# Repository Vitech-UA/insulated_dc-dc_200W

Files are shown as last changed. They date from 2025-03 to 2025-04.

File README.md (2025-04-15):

## Вигляд Віртуального пристрою. Без радіатора



## Вигляд Зібраного DC-DC. З радіатором
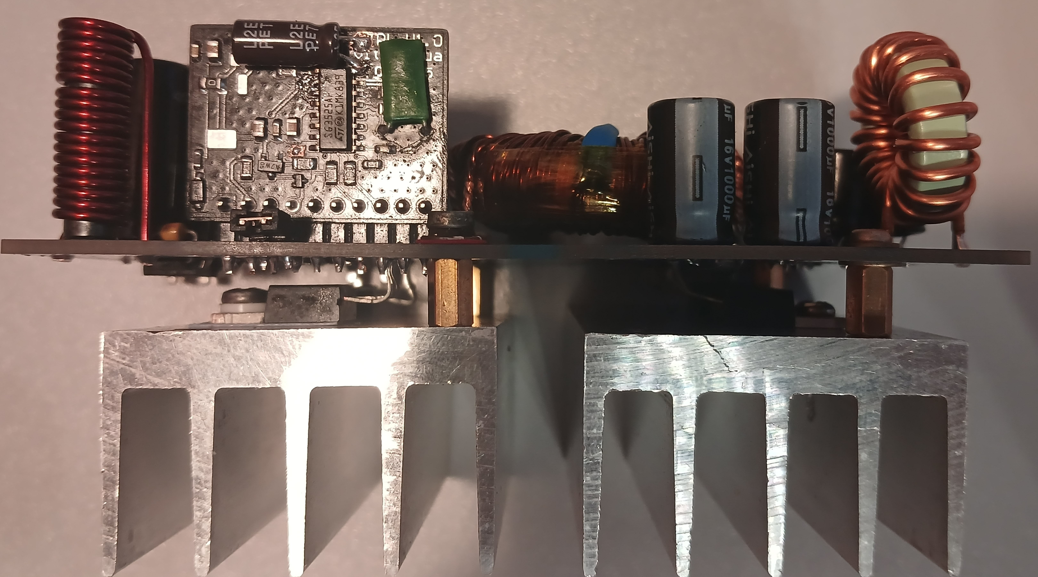
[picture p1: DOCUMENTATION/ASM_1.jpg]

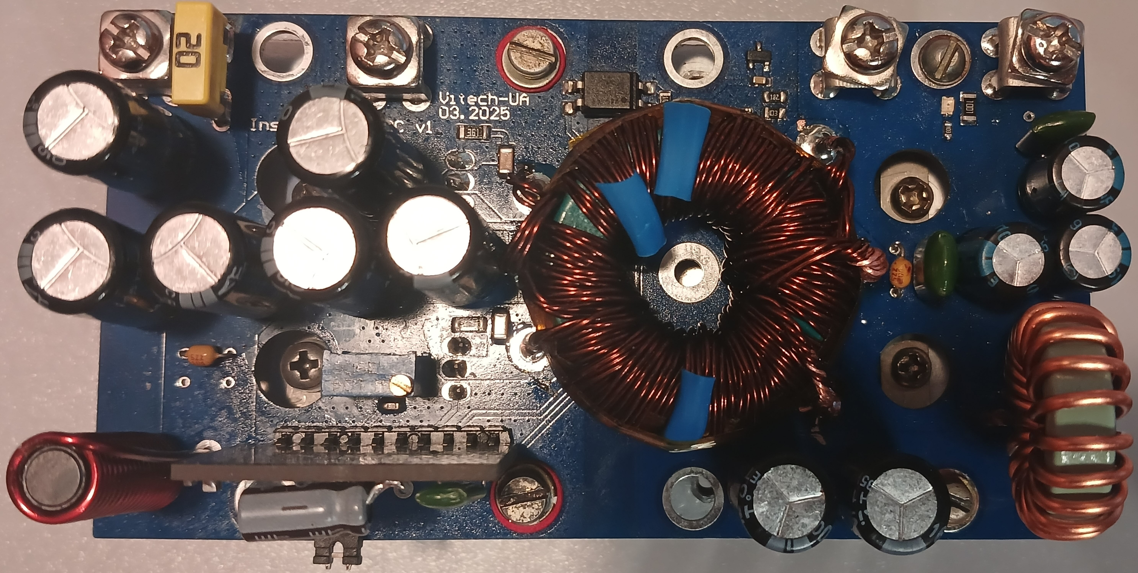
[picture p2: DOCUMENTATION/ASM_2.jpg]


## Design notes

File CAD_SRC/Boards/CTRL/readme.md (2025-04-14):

## Схема плати контроллера US3525


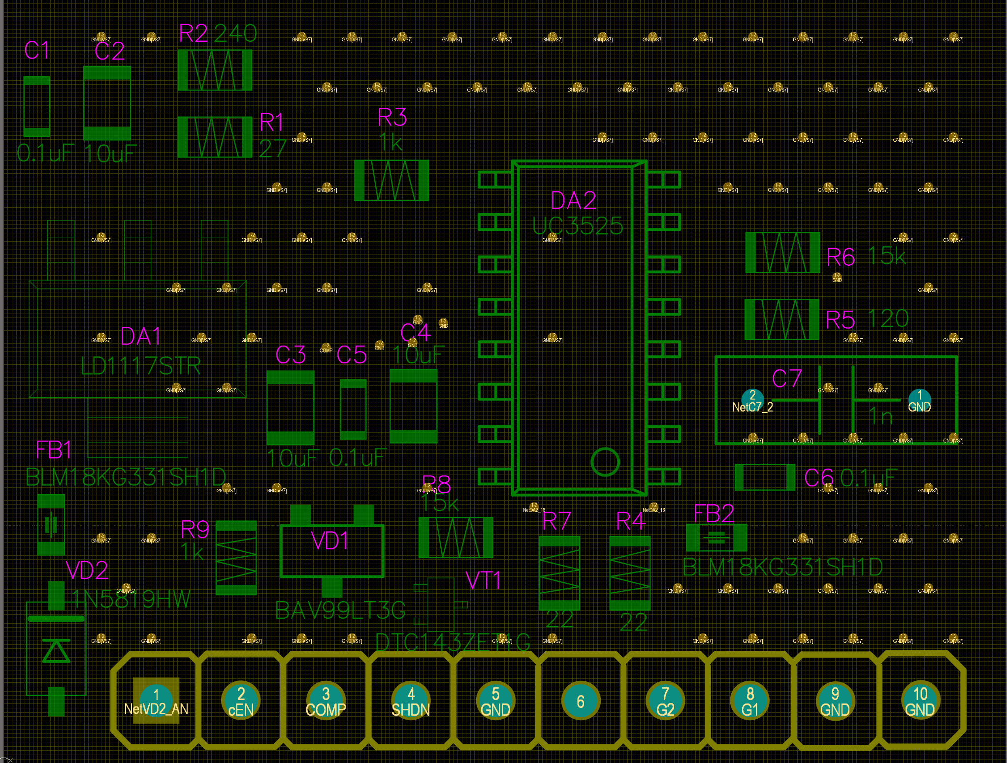
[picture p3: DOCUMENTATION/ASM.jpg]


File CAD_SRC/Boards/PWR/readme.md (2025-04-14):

## SCH PWRv1.0


## TOP VIEW PWRv1.0


## BOTTOM VIEW PWRv1.0


## SOLDERMAP
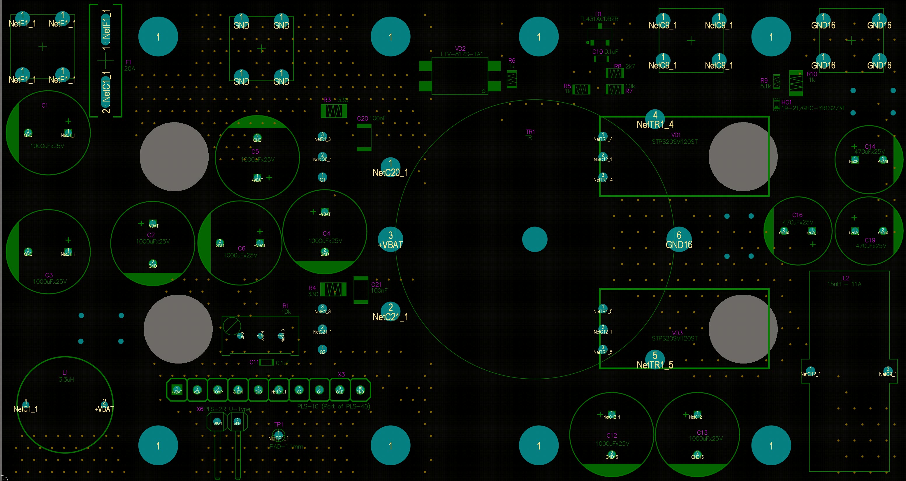
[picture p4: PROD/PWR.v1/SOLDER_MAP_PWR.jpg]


## Розрахунок трансформатора
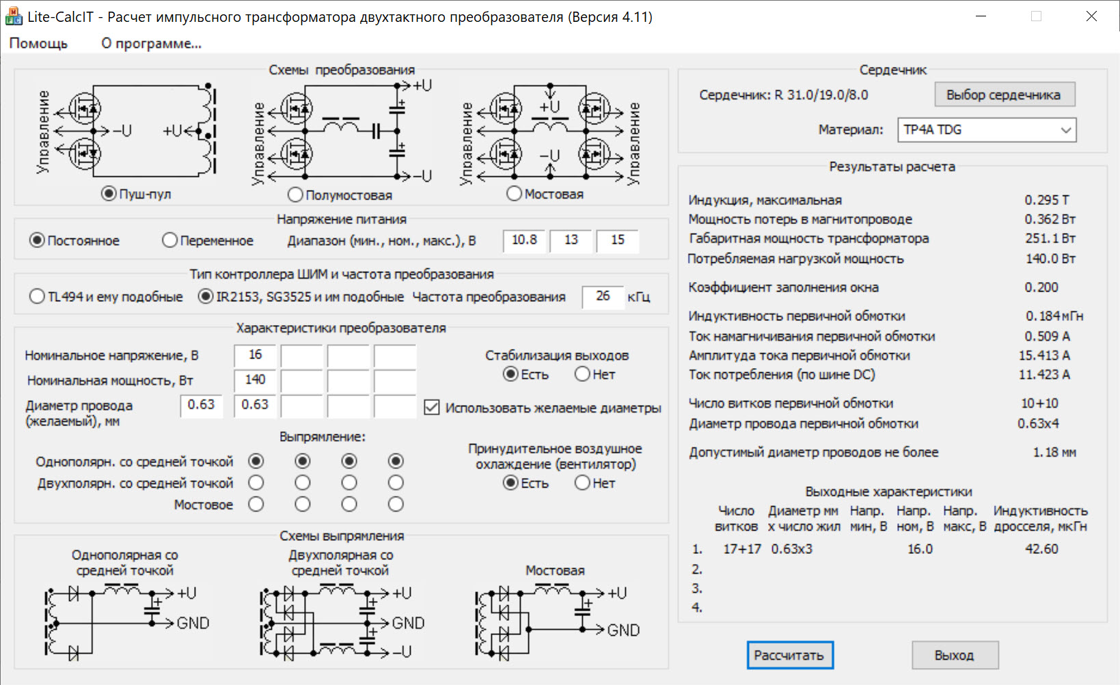
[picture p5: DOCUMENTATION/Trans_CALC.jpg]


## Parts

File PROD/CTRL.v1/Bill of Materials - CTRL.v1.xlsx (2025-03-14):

Project name | CTRL.PrjPcb
Revision | v1
Assembly variant | None
Engineer(s) | Vitech
Document timestamp | 14.03.2025
 | 23:17
Technical information |  |  |  |  |  |  |  | Additional information
Designator | Manufacturer | Part Number | Value | Tolerance | Voltage | Component Type | Package | Quantity | Comment | Description
C1, C5, C6 | Samsung Electro-Mechanics | CL10B104KB8NNNC | 0.1uF | ±10% | 50V | SMD | 0603 | 3 | 0.1uF | 100nF 50V X7R ±10% 0603 Ceramic Capacitor RoHS
C2 | TDK Corporation | C2012X5R1V106K125AC | 10uF | ±10% | 35V | SMD | 0805 | 1 | 10uF | 10uF 35V X5R ±10% 0805 Low ESL Ceramic Capacitor RoHS
C3, C4 | TDK Corporation | C2012X5R1E106M085AC | 10uF | ±20% | 25V | SMD | 0805 | 2 | 10uF | 10uF 25V X5R ±20% 0805 Ceramic Capacitor RoHS
C7 | Murata | GRM31CR71E106KA12L | 1n | 10 % | *V | THT | 1206 | 1 | 1n | Multilayer Ceramic Capacitors MLCC - SMD/SMT 10 uF 25 VDC 10% 1206 X7R
DA1 | STMicroelectronics | LD1117STR |  |  |  | SMD | SOT-223 | 1 | LD1117STR | Adjustable Low Drop Positive Voltage Regulator, 1.25V to 15V, 800mA
DA2 | Texas | UC3825 |  |  |  | SMD | DIP16 | 1 | UC3525 | Buck, Push-Pull Regulator Positive Output Step-Down, Step-Up/Step-Down DC-DC Controller IC 16-DIP/16-SOIC
FB1, FB2 | Murata Electronics | BLM18KG331SH1D | 330 Ohms @ 100MHz | ±25% |  | SMD | 0603 | 2 | BLM18KG331SH1D | 330 Ohms @ 100 MHz Power Line Ferrite Bead 0603, 1.7A 80mOhm
R1 | Yageo | RC0805JR-0722RL | 27 | ±5% | 150V | SMD | 0805 | 1 | 27 | 22 Ohms ±5%, 1/8W 0805 Thick Film Resistor
R2 | Yageo | RC0805JR-0722RL | 240 | ±5% | 150V | SMD | 0805 | 1 | 240 | 22 Ohms ±5%, 1/8W 0805 Thick Film Resistor
R3, R9 | Yageo | RC0805JR-0722RL | 1k | ±5% | 150V | SMD | 0805 | 2 | 1k | 22 Ohms ±5%, 1/8W 0805 Thick Film Resistor
R4, R7 | Yageo | RC0805JR-0722RL | 22 | ±5% | 150V | SMD | 0805 | 2 | 22 | 22 Ohms ±5%, 1/8W 0805 Thick Film Resistor
R5 | Yageo | RC0805JR-0722RL | 120 | ±5% | 150V | SMD | 0805 | 1 | 120 | 22 Ohms ±5%, 1/8W 0805 Thick Film Resistor
R6, R8 | Yageo | RC0805JR-0722RL | 15k | ±5% | 150V | SMD | 0805 | 2 | 15k | 22 Ohms ±5%, 1/8W 0805 Thick Film Resistor
VD1 | Onsemi | BAV99LT3G |  |  | 100V | SMD | SOT-23 | 1 | BAV99LT3G | Diode Array 1 Pair Series Connection, Standard, 100V, 215mA (DC), SOT-23
VD2 | Nexperia USA | 1N5819HW |  |  | 75V | SMD | SOD-123 | 1 | 1N5819HW | Diode Standart 75V 215mA, SOD-123
VT1 | Onsemi | DTC143ZET1G |  |  |  | SMD | SC-75 | 1 | DTC143ZET1G | 50V, 100mA Low Vce(sat) NPN Digital Transistor, Pre-Biased 4.7k/47k (with built-in resistors)
X1 | Connfly | DS1021-10SF11 |  |  |  | PTH |  | 1 | PLS-10 (Part of PLS-40) | 10 Pin 2.54mm Male Header, Vertical, 3mm and 6.1mm, PLS-5

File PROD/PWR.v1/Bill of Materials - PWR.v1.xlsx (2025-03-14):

Product name | INS.DCDC |  |  |  |  |  |  |  |  |  | Template version 1.0.1
Project name | PWR.PrjPcb
Revision | v1
Assembly variant | None
Engineer(s) | Starovit
Document timestamp | 14.03.2025
 | 23:23
Technical information |  |  |  |  |  |  |  | Additional information
Designator | Manufacturer | Part Number | Value | Tolerance | Voltage | Component Type | Package | Quantity | Comment | Description
C1, C2, C3, C4, C5, C6, C12, C13 | Kemet | ESH108M025AH4AA | 1000uF | ±20% | 25V | PTH | D10x20mm | 8 | 1000uFx25V | 1000uF 25V ±20% Aluminum Electrolytic Capacitors Radial, 2000 Hrs @ 105°C, 740mA Ripple Current
C7, C8, C9, C15, C17, C18 | Murata | GRM31CR71E106KA12L | 0.1uF | 10 % | 25V | THT | 1206 | 6 | *uF | Multilayer Ceramic Capacitors MLCC - SMD/SMT 10 uF 25 VDC 10% 1206 X7R
C10, C11 | Samsung Electro-Mechanics | CL10B104KB8NNNC | 0.1uF | ±10% | 50V | SMD | 0603 | 2 | 0.1uF | 100nF 50V X7R ±10% 0603 Ceramic Capacitor RoHS
C14, C16, C19 | Koshin | KS-025V471MF130 | 470uF | ±20% | 25V | PTH | D8x13mm | 3 | 470uFx25V | 470uF 25V ±20% D8x13mm Conductive Polymer Aluminum Solid Capacitor, 2000 Hrs @ 105°C, 4100mA Ripple Current
C20, C21 | Walsin | 1206B102K102CG | 1nF | ±10% | 1000V | SMD | 1206 | 2 | 100nF | 1nF 1000V X7R ±10% 1206 Ceramic Capacitor RoHS
D1 | Texas Instruments | TL431ACDBZR |  |  |  | SMD | SOT-23 | 1 | TL431ACDBZR | Adjustable Precision Shunt Regulator, Accuracy 1%, SOT-23-3
F1 |  |  |  |  |  |  |  | 1 | 20A | Fuse MAXI Size
HG1 | Everlight Electronics | 19-21/GHC-YR1S2/3T |  |  |  | SMD | 0603 | 1 | 19-21/GHC-YR1S2/3T | Indication LED, Green 528nm, Clear, SMD 0603, Vf 2.7-3.7V, 112 - 285mcd @ 20mA, 110°
J1 | Connfly | DS1022-1x2RUF1 |  |  |  | PTH |  | 1 | PLS-2R U-Type | 2 pin Male Header, Right Angle, 2.54mm, PTH, PLS-2R, U-type
L1 | Bourns Inc. | RLB0914-3R3ML-ND | 3.3 uH | ±20% |  |  | THT | 1 | 3.3uH | Дросель з магазину Coretech
L2 | Bourns Inc. | RLB0914-3R3ML-ND | 15 uH | ±20% |  |  | THT | 1 | 15uH
R1 | Bourns | 3296W-1-103LF | 10k | ±10% |  | PTH | 4.83x9.53mm | 1 | 10k | 10 kOhms ±10% Trimmer Resistor, 0.5W, Through Hole 3/8", 4.83x9.53mm, 10.03mm Height
R2, R11, R12 | Bourns | CRA2512-FZ-R030ELF | 40mOhm | ±1% | NONE | SMD | 2512 | 3 | 40mOhm | 30 mOhms ±1%, 3W 2512 Metal Strip Current Sense Chip Resistor
R3, R4 | Vishay | CRCW120675R0FKEAC | 330 | ±1% | 200V | SMD | 1206 | 2 | 330 | 75 Ohms ±1%, 1/4W 1206 Thick Film Resistor
R5, R6 | Yageo | RC0805JR-0722RL | 1k | ±5% | 150V | SMD | 0805 | 2 | 1k | 22 Ohms ±5%, 1/8W 0805 Thick Film Resistor
R7 | Yageo | RC0805JR-0722RL | 10k | ±5% | 150V | SMD | 0805 | 1 | 22 | 22 Ohms ±5%, 1/8W 0805 Thick Film Resistor
R8 | Yageo | RC0805JR-0722RL | 2k7 | ±5% | 150V | SMD | 0805 | 1 | 2k7 | 22 Ohms ±5%, 1/8W 0805 Thick Film Resistor
R9 | Yageo | RC0603FR-075K1L | 5.1k | ±1% | 75V | SMD | 0603 | 1 | 5.1k | 5.1 kOhms ±1%, 1/10W 0603 Thick Film Resistor
R10 | Vishay | CRCW120675R0FKEAC | 1k | ±1% | 200V | SMD | 1206 | 1 | 1k | 75 Ohms ±1%, 1/4W 1206 Thick Film Resistor
TR1 | Handmade | RLB0914-3R3ML-ND |  | ±20% |  |  |  | 1 | TR
VD1, VD3 | STMicroelectronics | STPS20SM120ST |  |  | 120V | PTH | TO-220AB | 2 | DIODE SCHOTTKY | Diode Schottky Array 1 Pair Common Cathode, 120V 20A, TO-220
VD2 | Lite-On Optoelectronics | LTV-817S-TA1 |  |  |  | SMD | SSOP-4 | 1 | LTV-817S-TA1 | 1-Channel Photocoupler, 5kV, SSOP-4
VD5, VD6, VD7 | Onsemi | SS34 |  |  | 40V | SMD | SMC | 3 | SS34 | Diode Schottky 40V 3A, SMC
VT1, VT2 |  | IRF3205 |  |  |  | SMD | D-PAK | 2 | AOD403 | N-MOSFET; полевой;
X1, X2, X4, X5 | China | PCB-2CM3 |  |  |  | PTH |  | 4 | PCB-2CM3 | Гвинтова клема для друкарського монтажу, 40 А Матеріал - латунь луджена 0.8 мм, гвинт в комплекті. Піни 5x7mm
X3 | Connfly | DS1021-10SF11 |  |  |  | PTH |  | 1 | PLS-10 (Part of PLS-40) | 10 Pin 2.54mm Male Header, Vertical, 3mm and 6.1mm, PLS-5

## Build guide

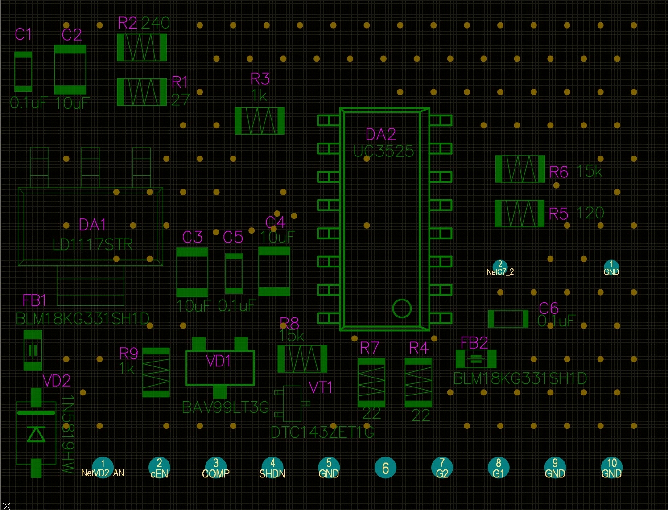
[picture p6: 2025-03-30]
PROD/CTRL.v1/SOLDER_MAP_CTRL.jpg

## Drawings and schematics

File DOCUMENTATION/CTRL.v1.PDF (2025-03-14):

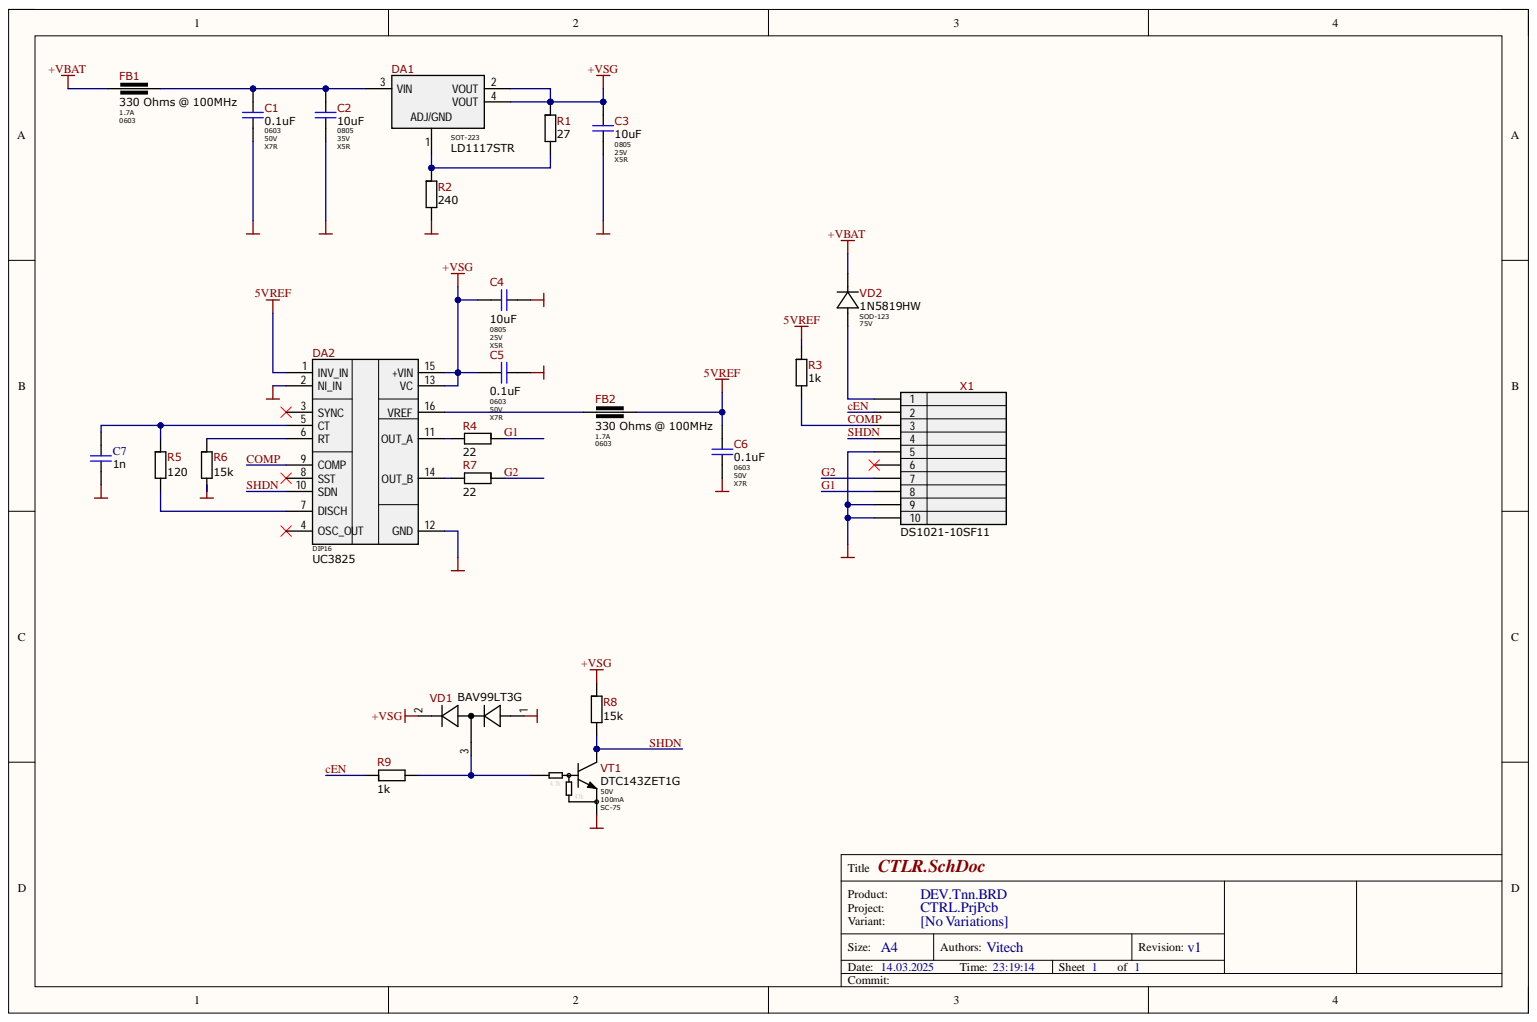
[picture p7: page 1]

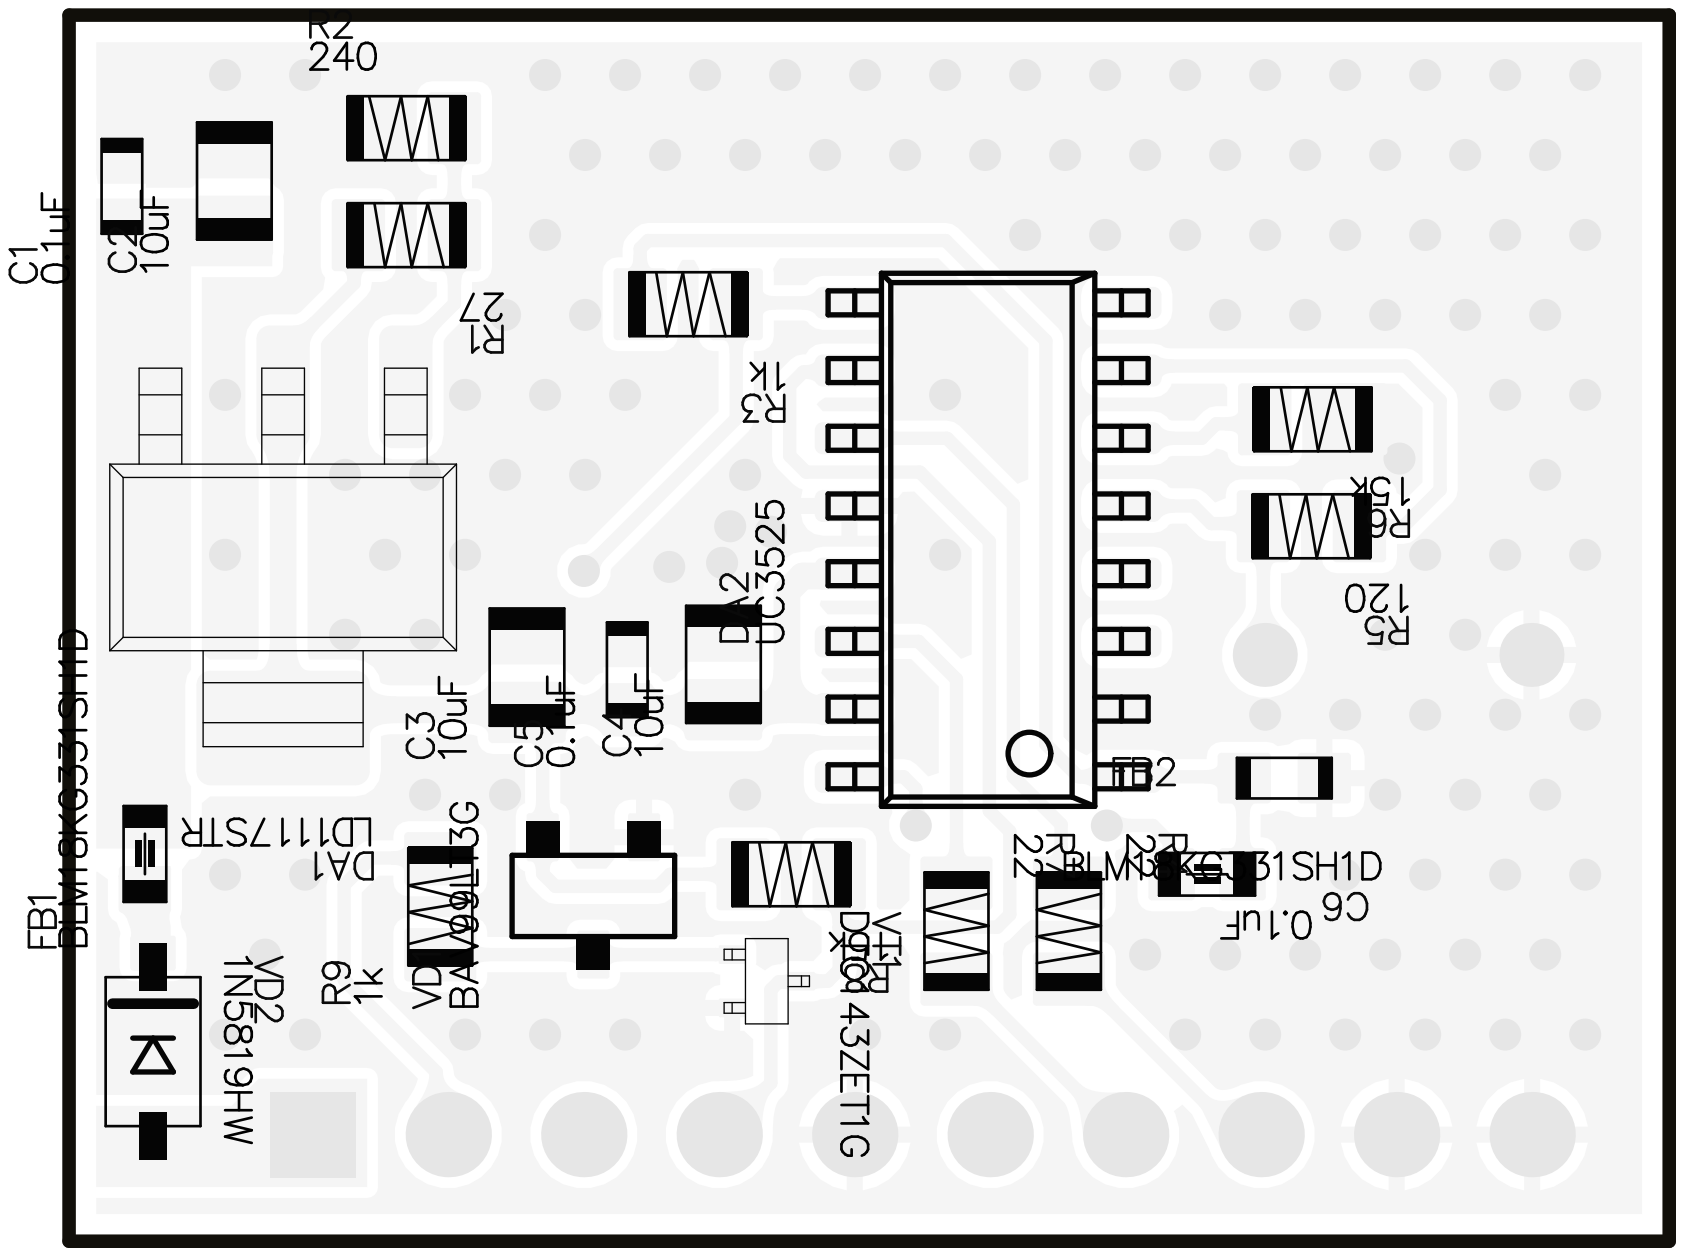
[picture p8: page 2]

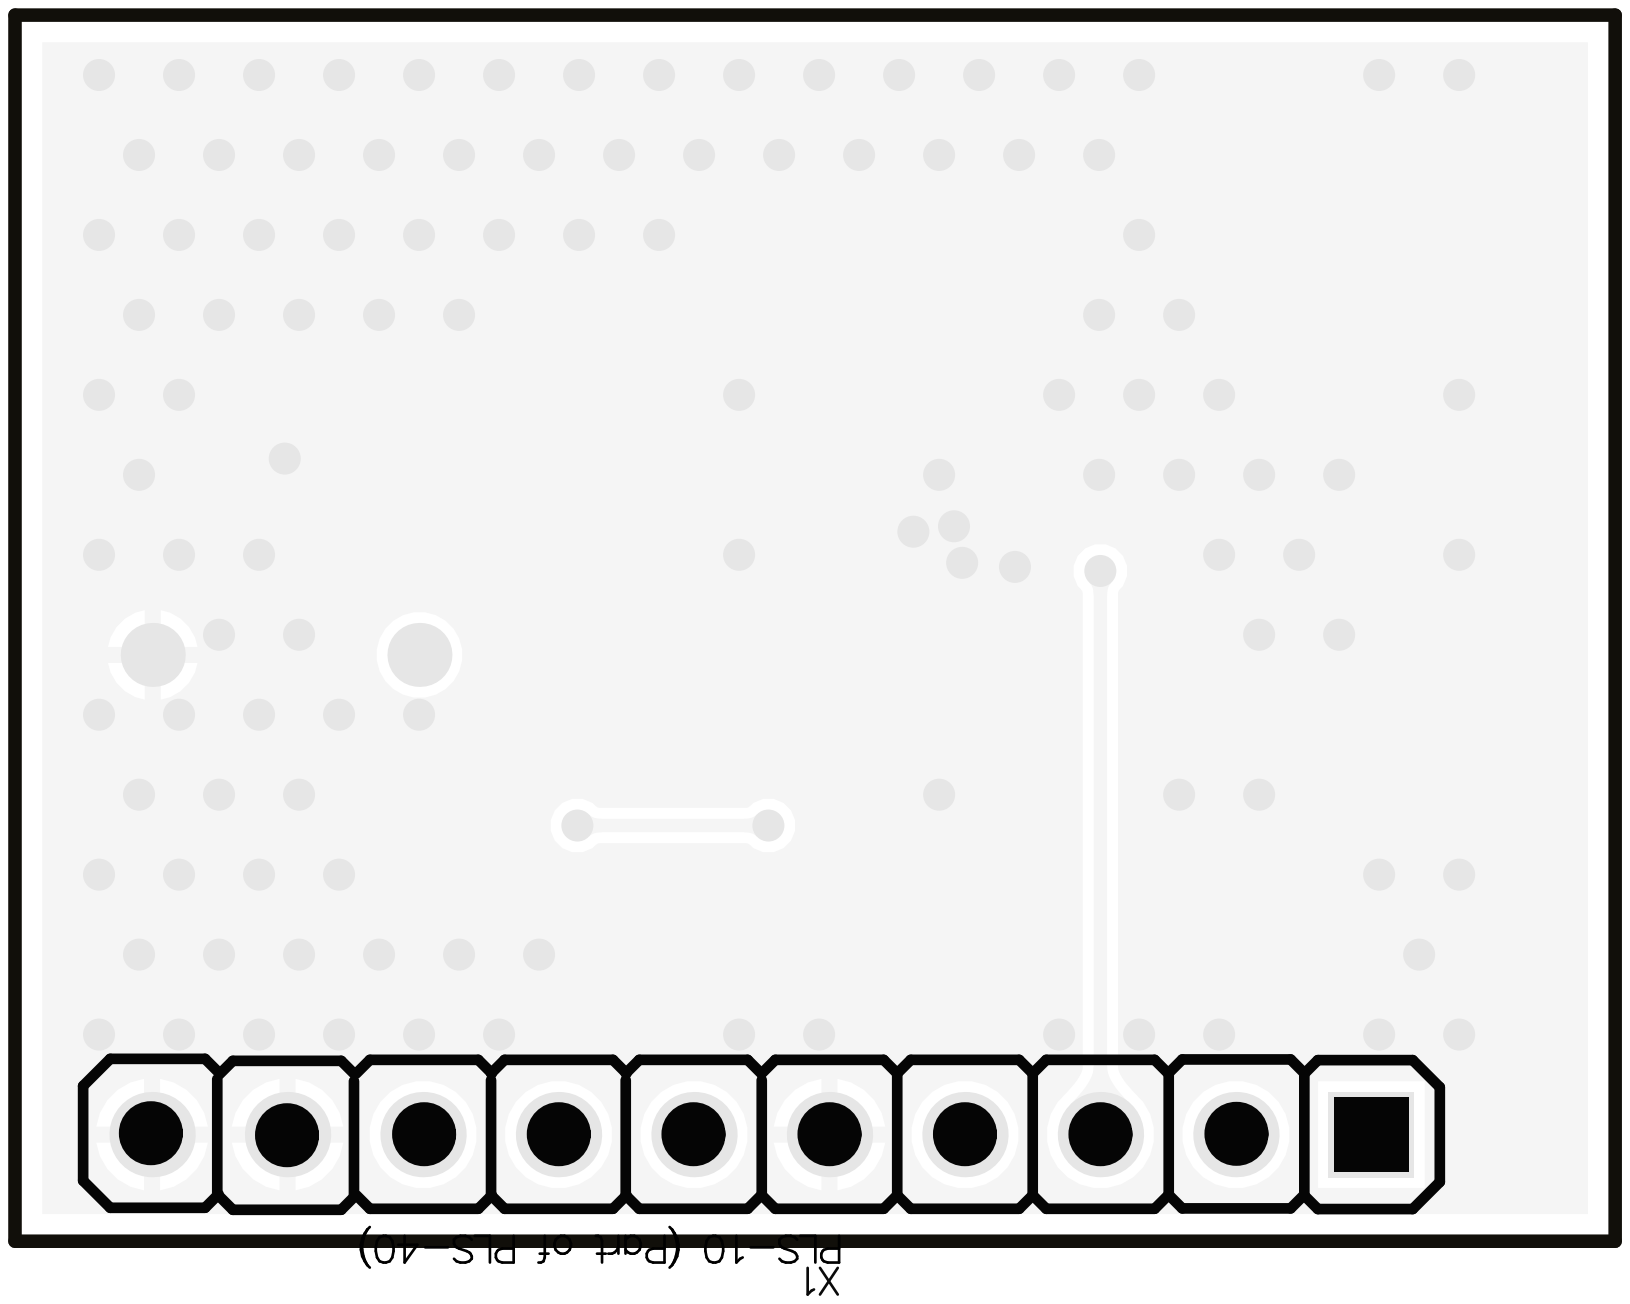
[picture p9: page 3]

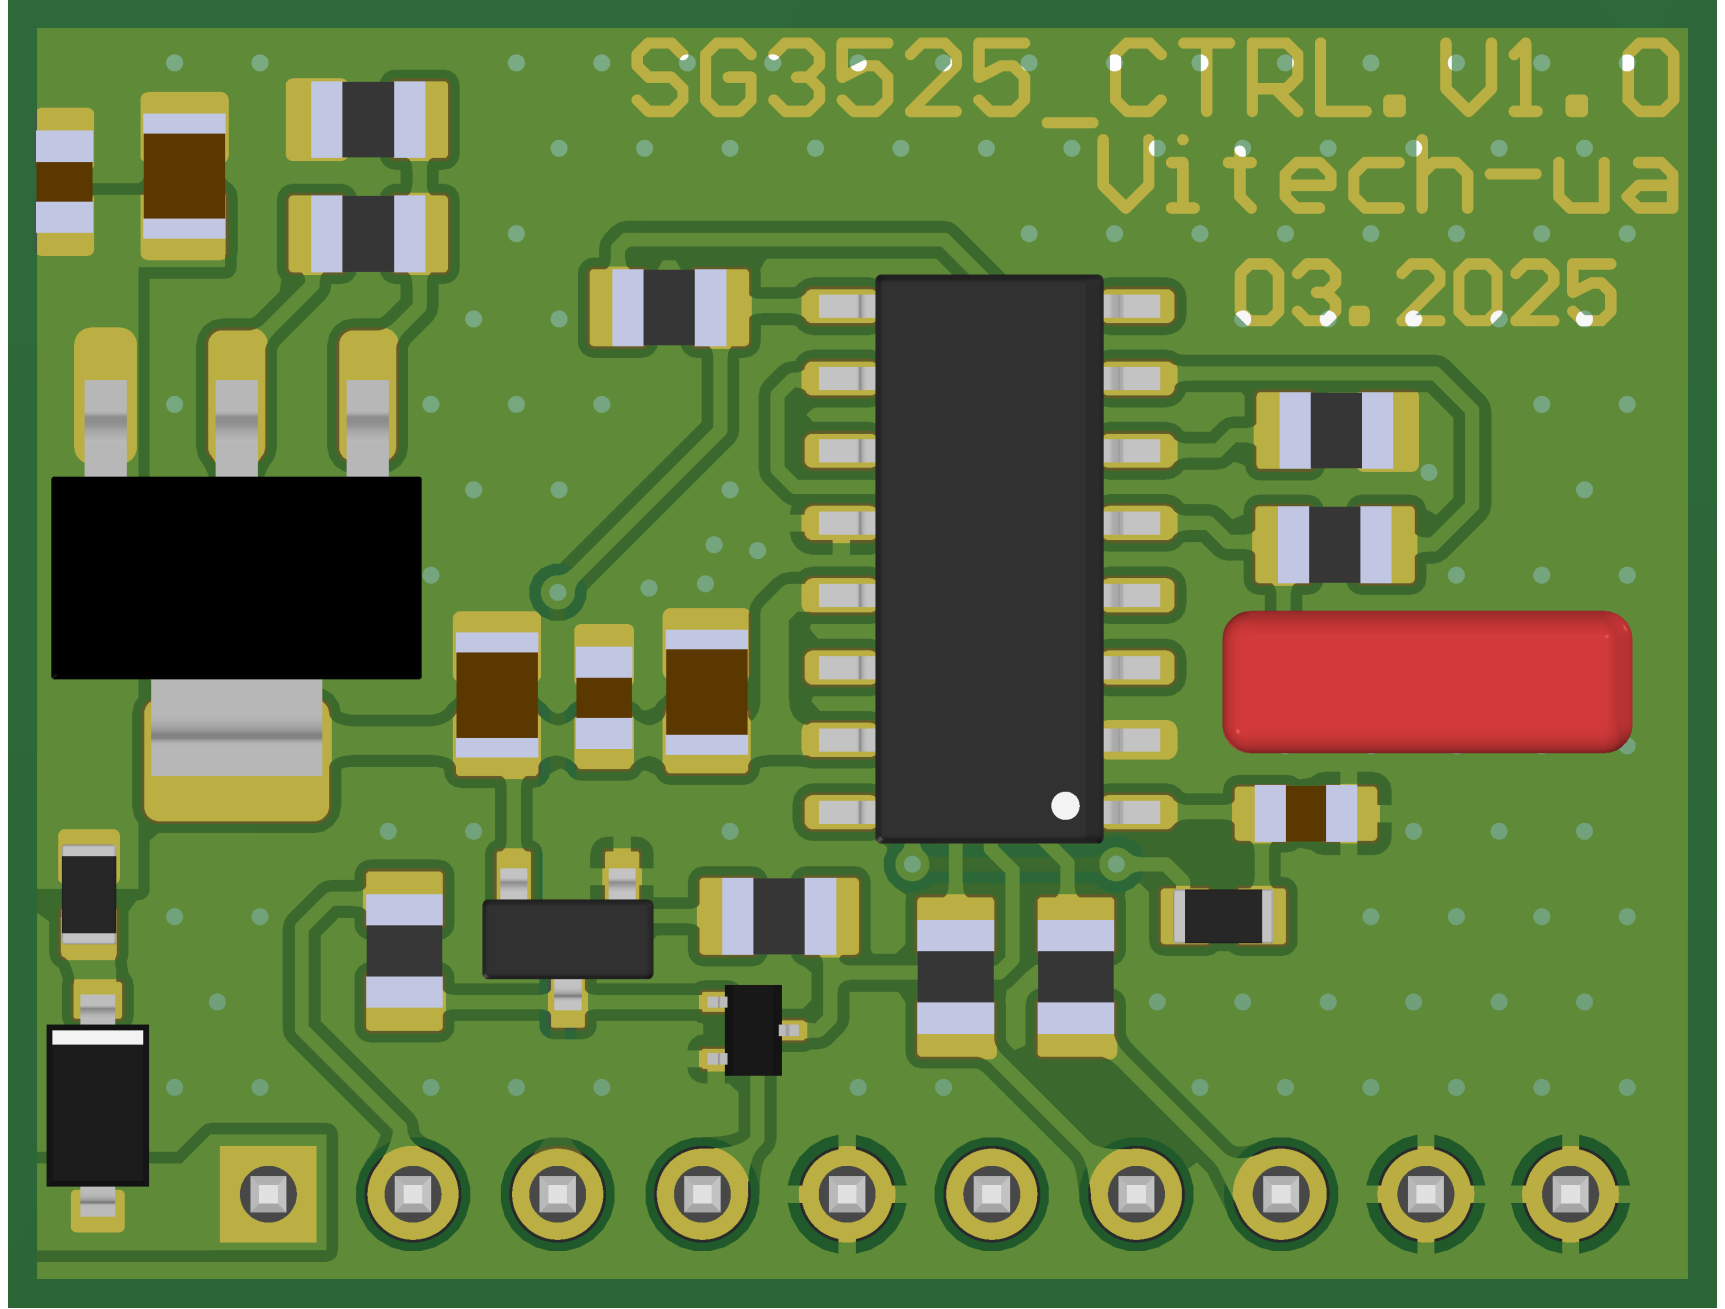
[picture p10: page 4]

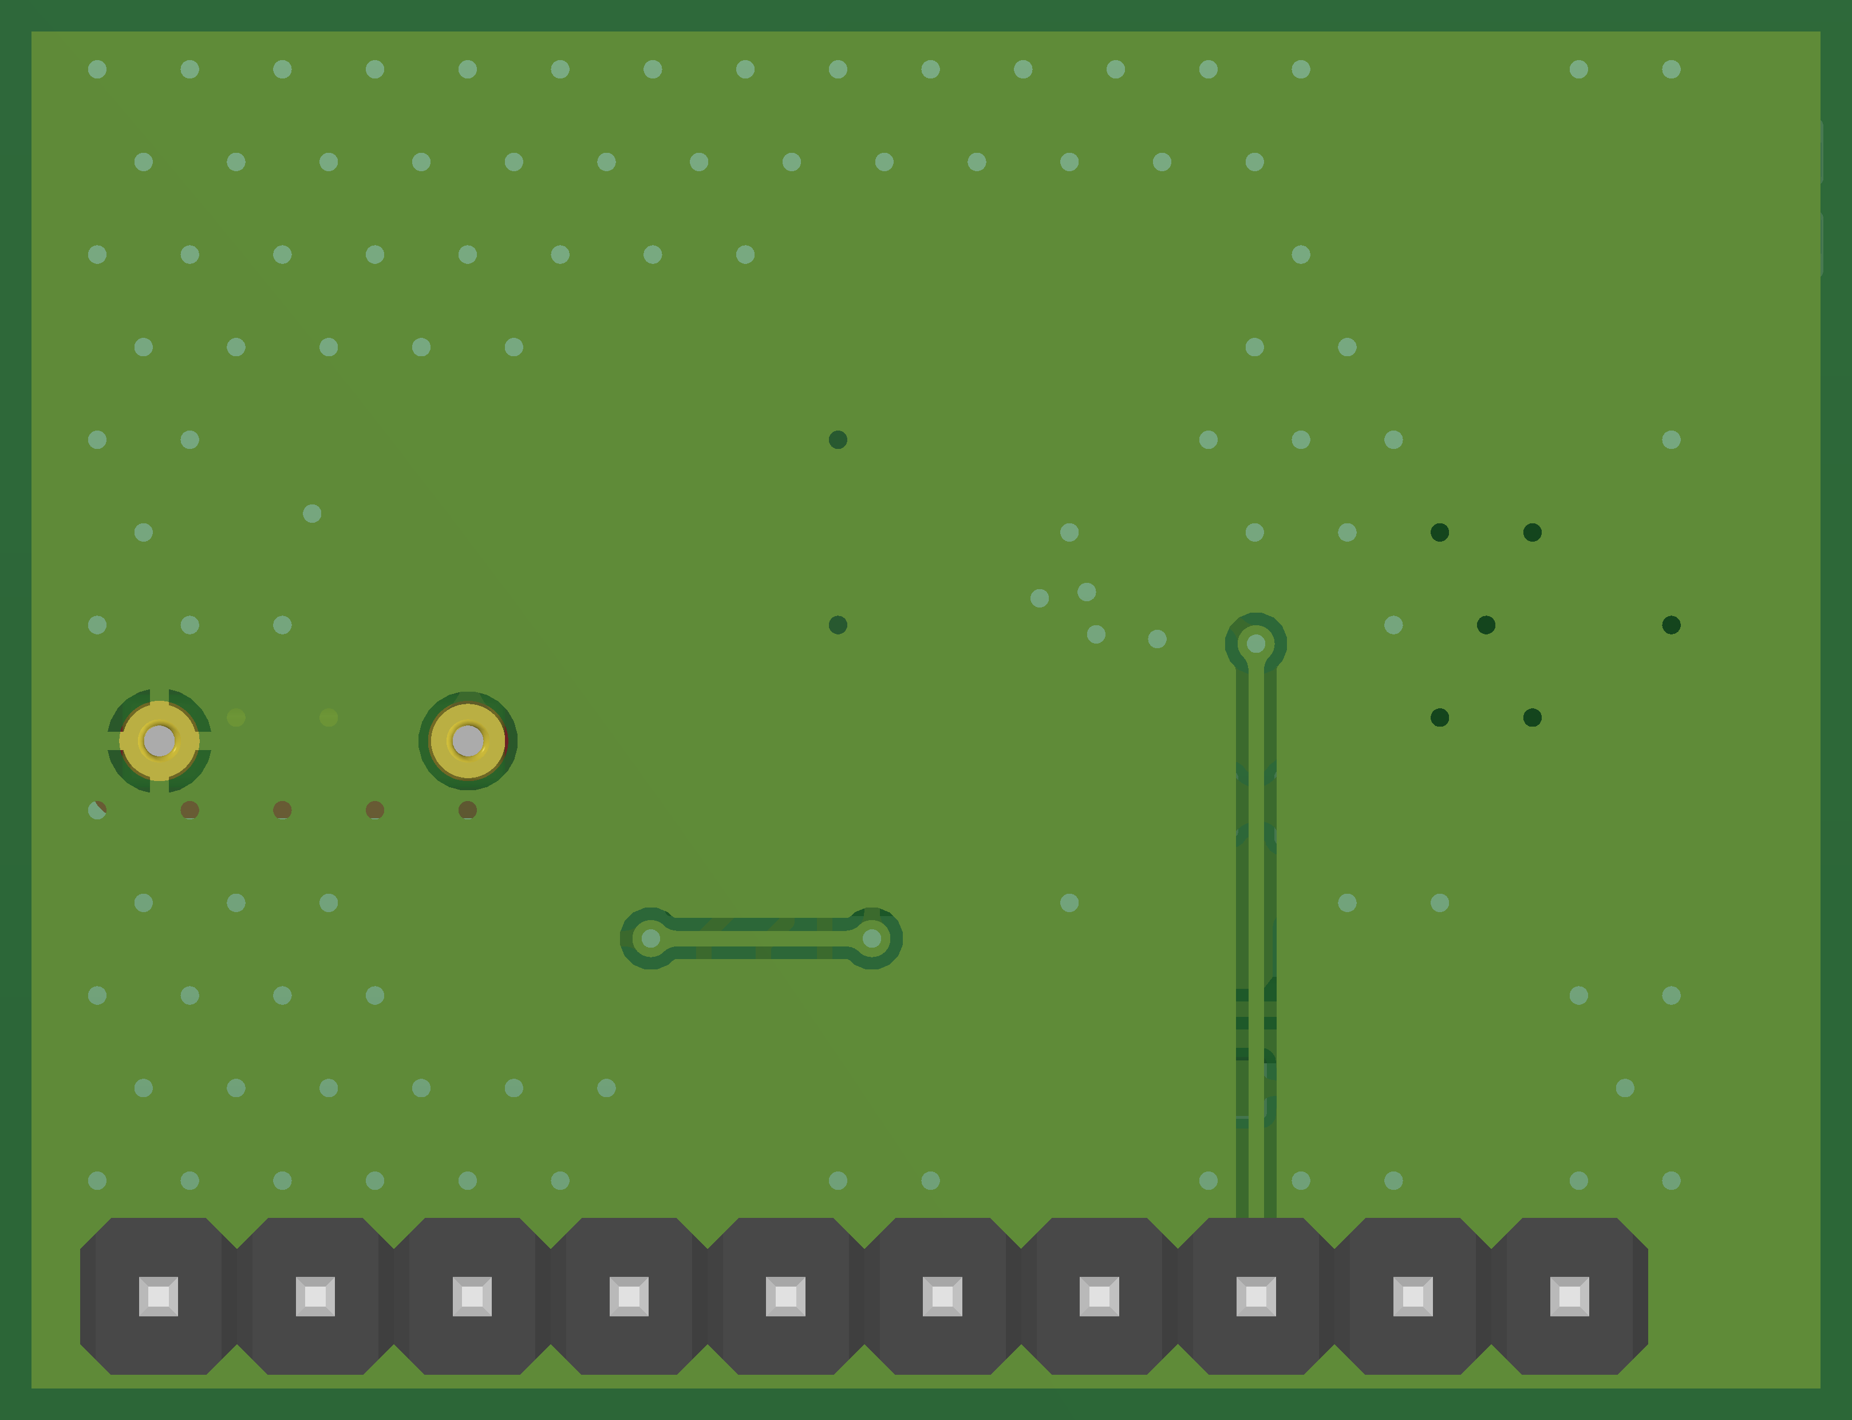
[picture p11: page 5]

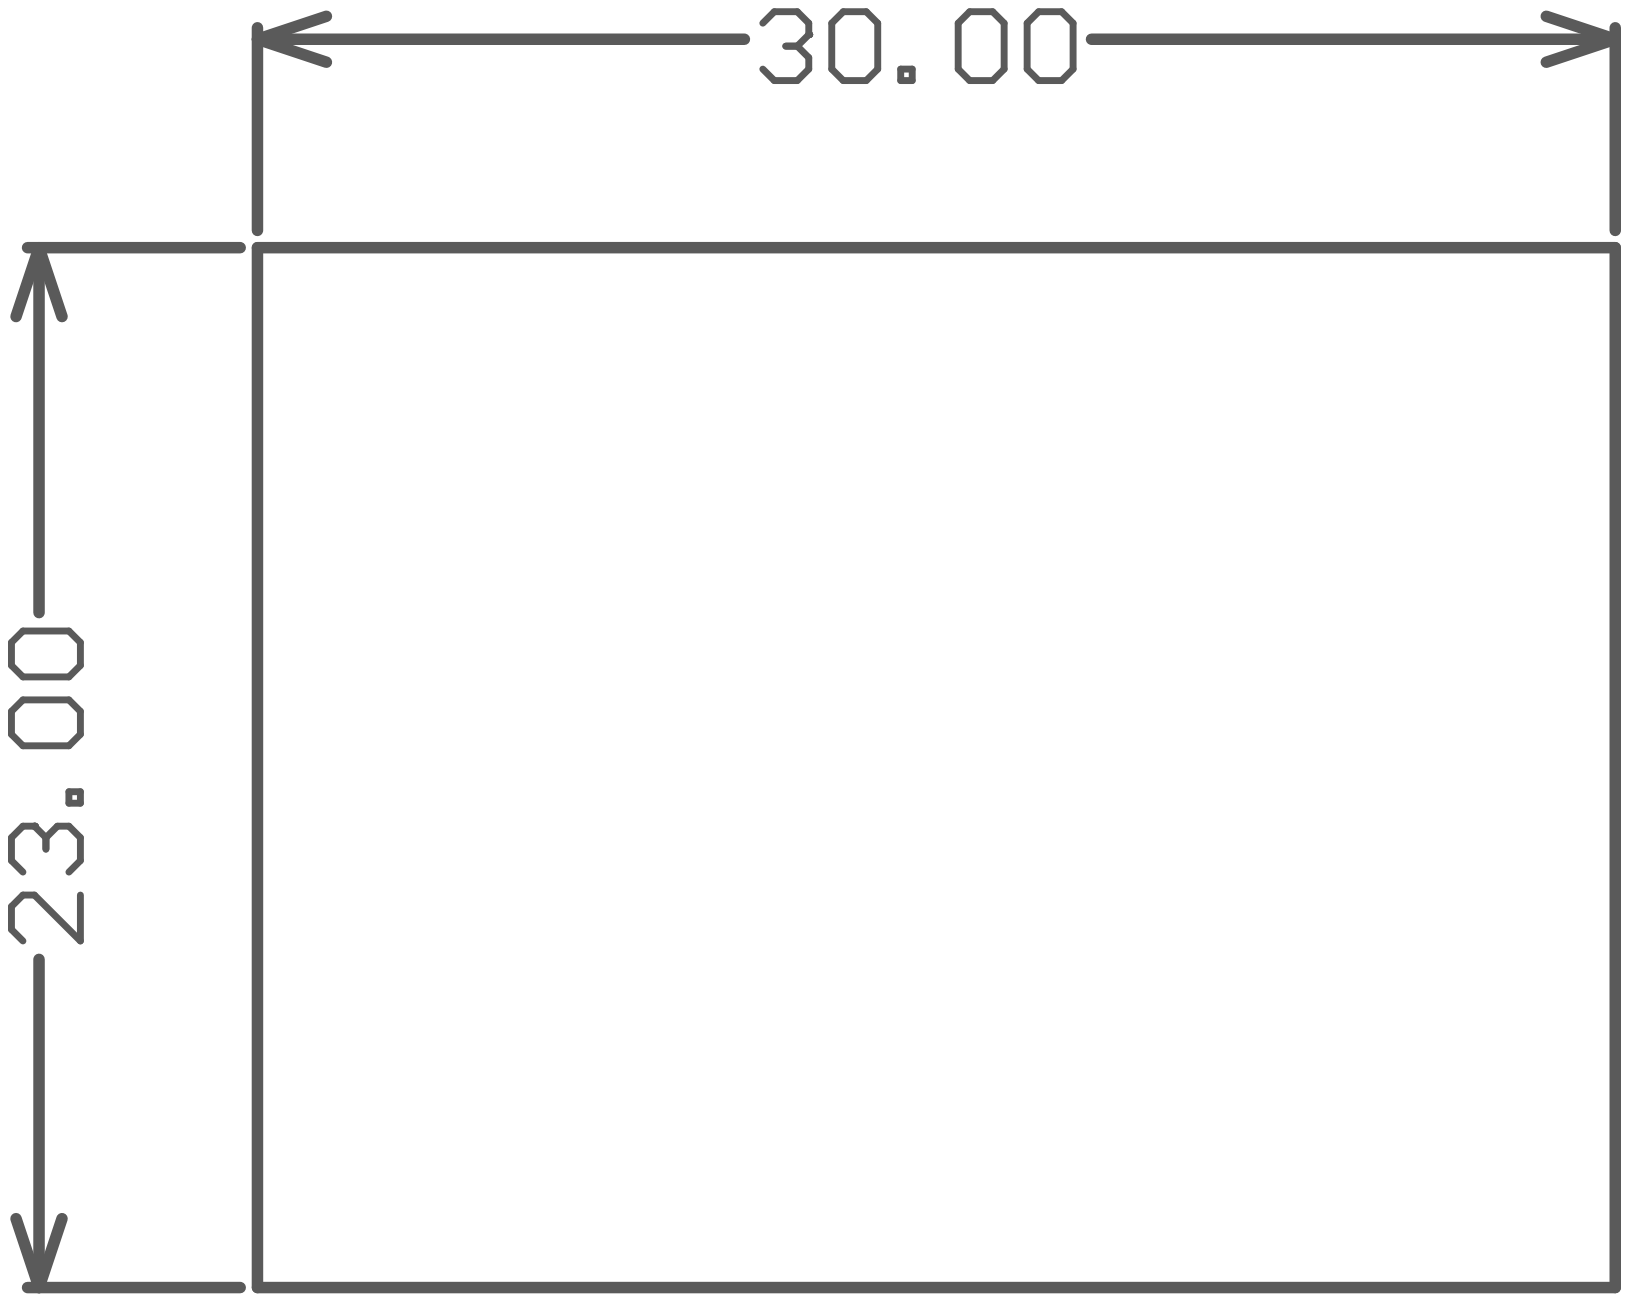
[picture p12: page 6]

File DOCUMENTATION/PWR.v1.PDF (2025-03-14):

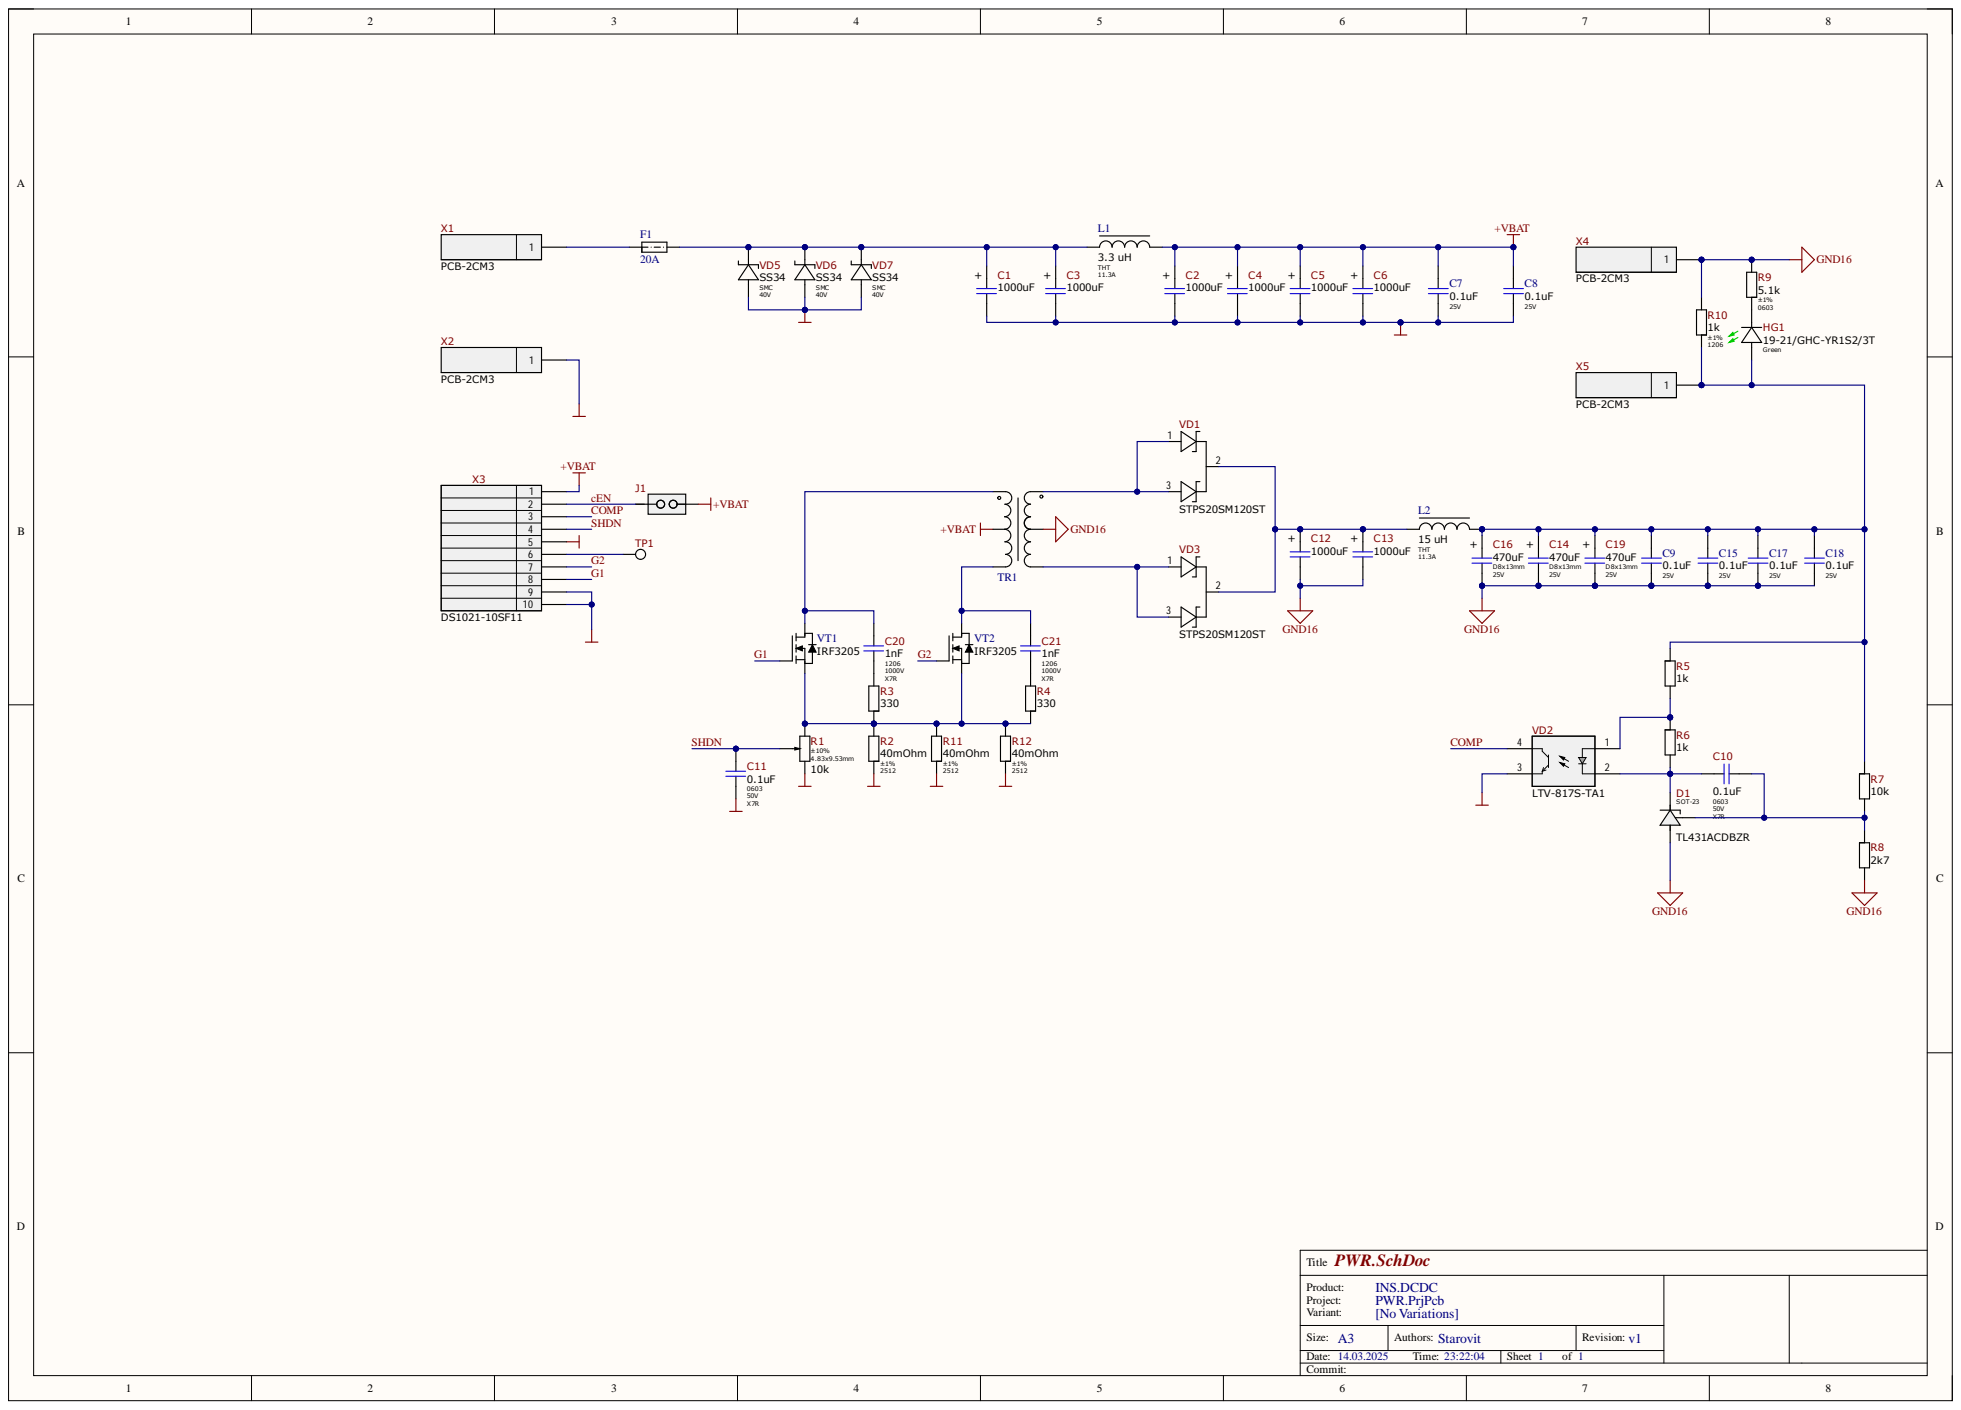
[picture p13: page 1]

10

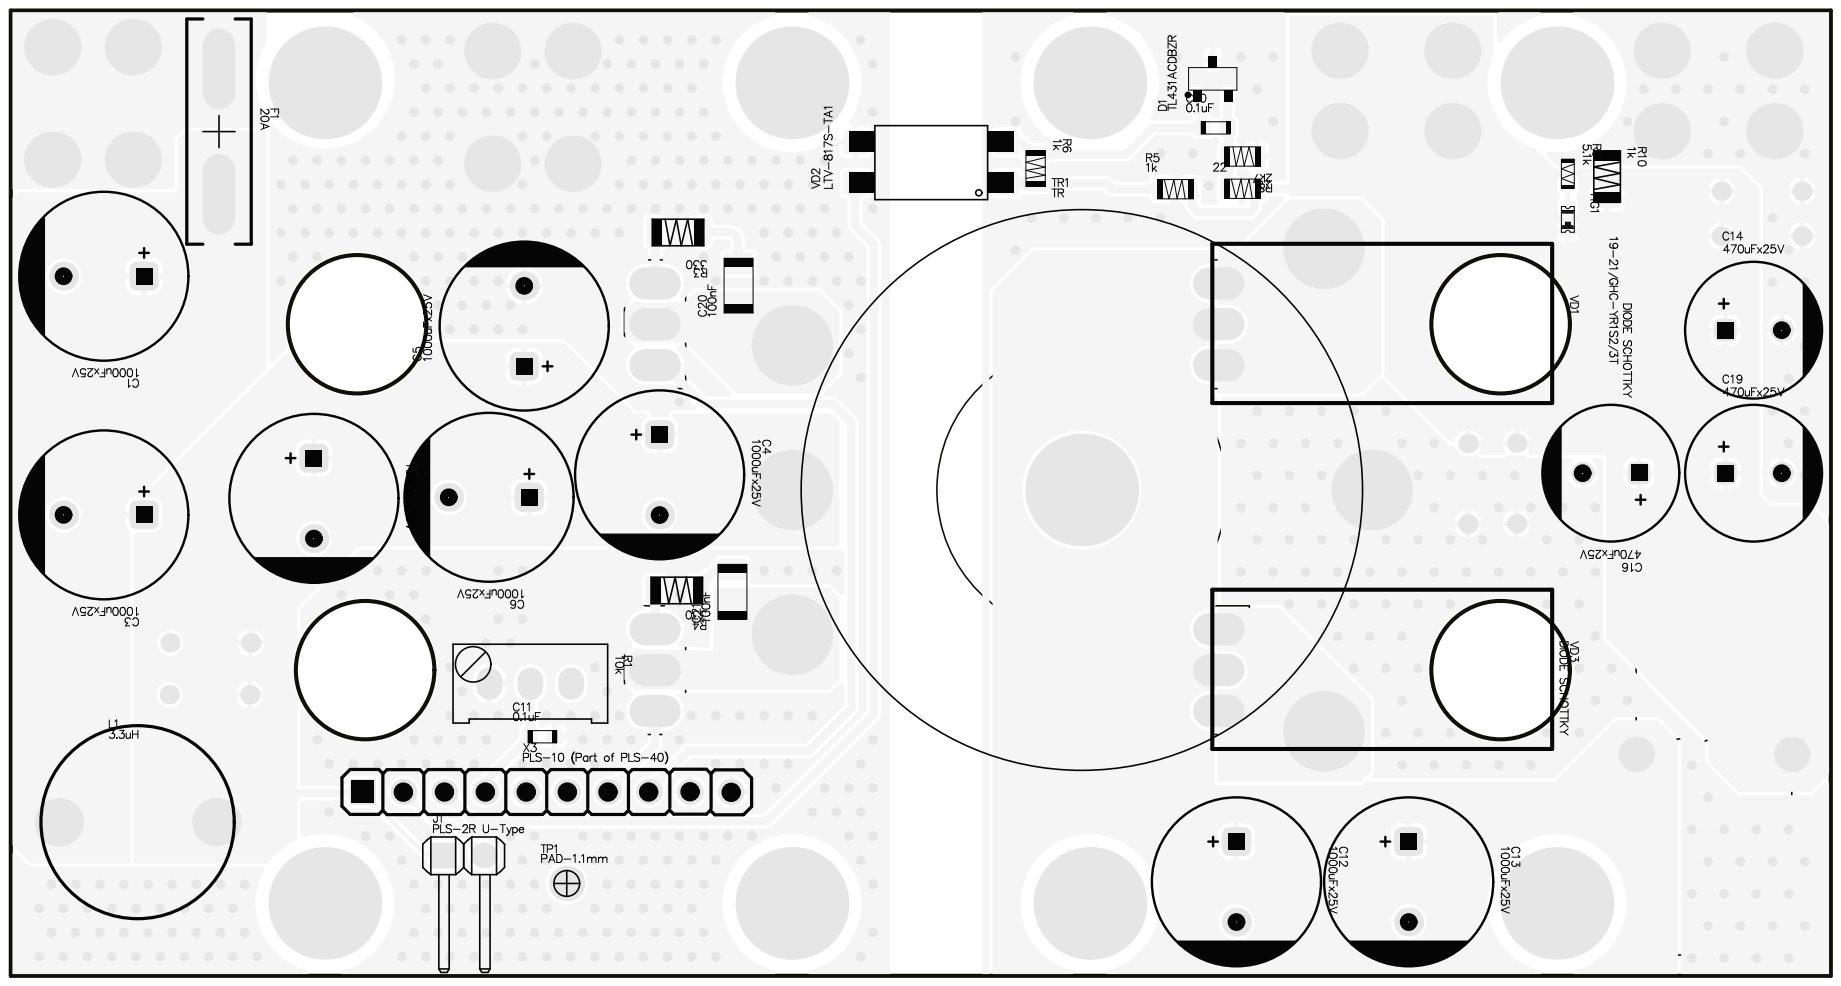
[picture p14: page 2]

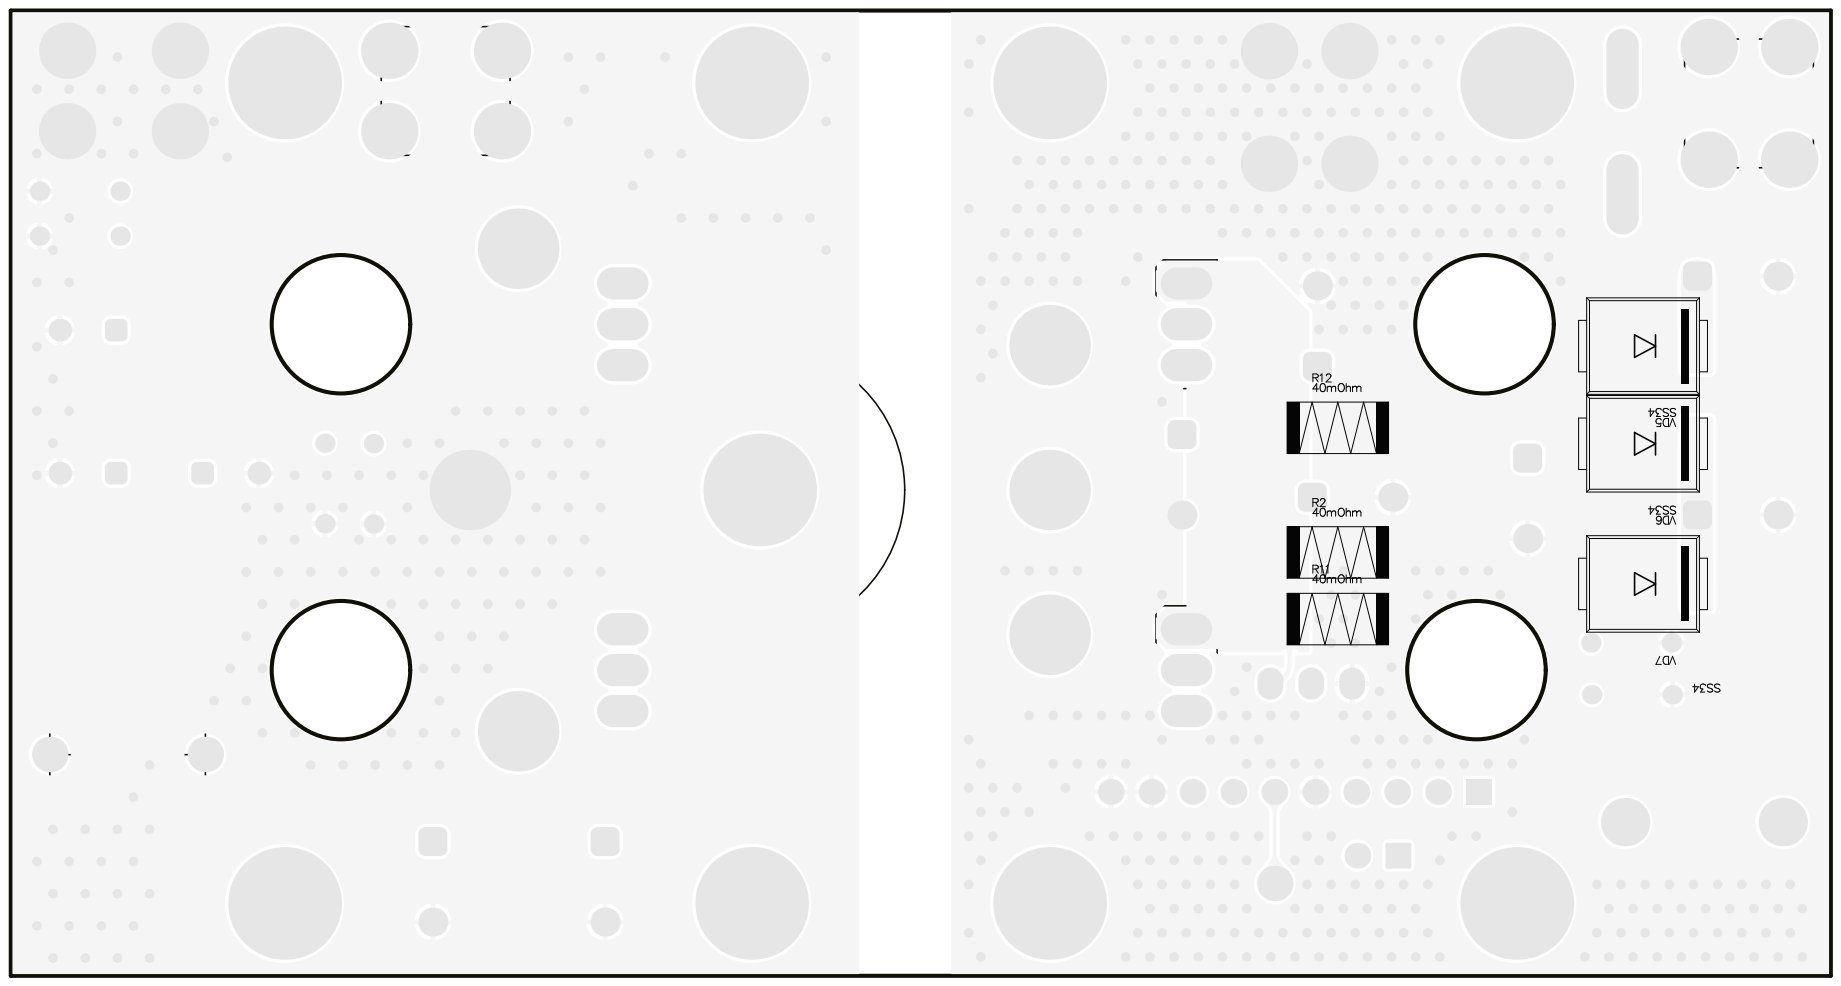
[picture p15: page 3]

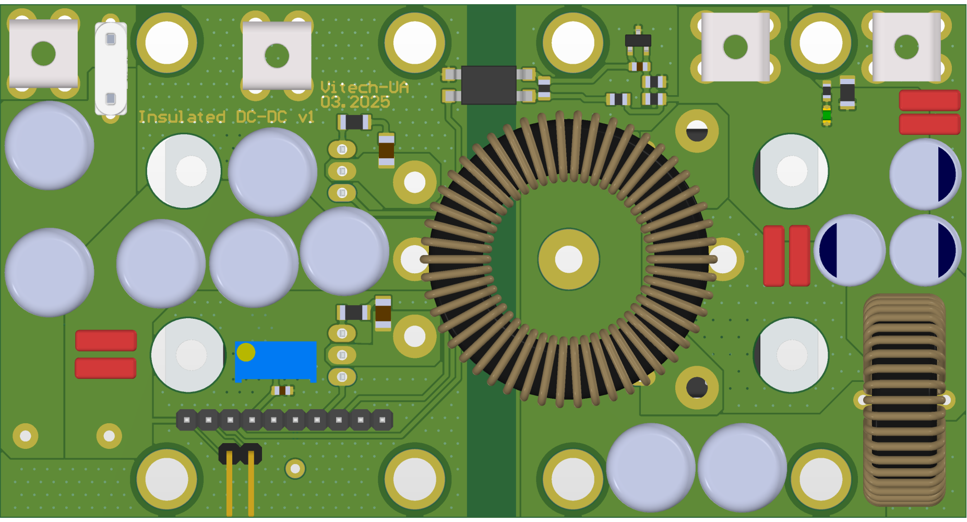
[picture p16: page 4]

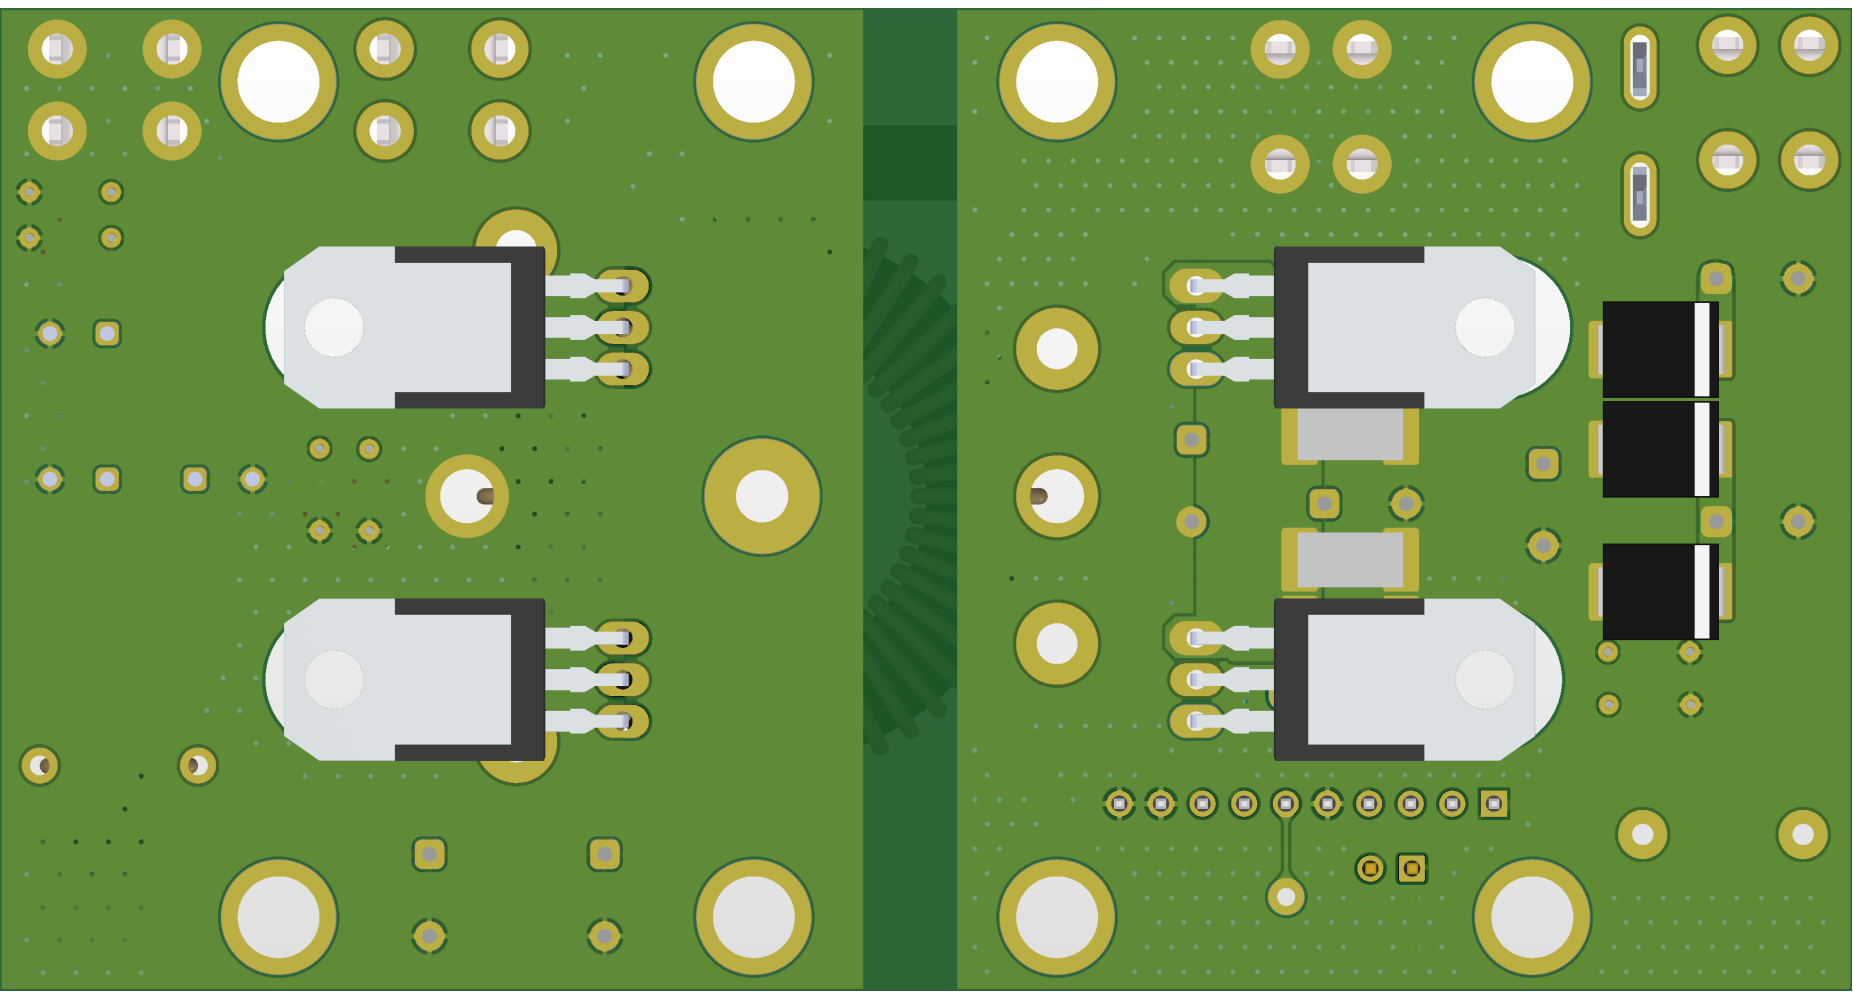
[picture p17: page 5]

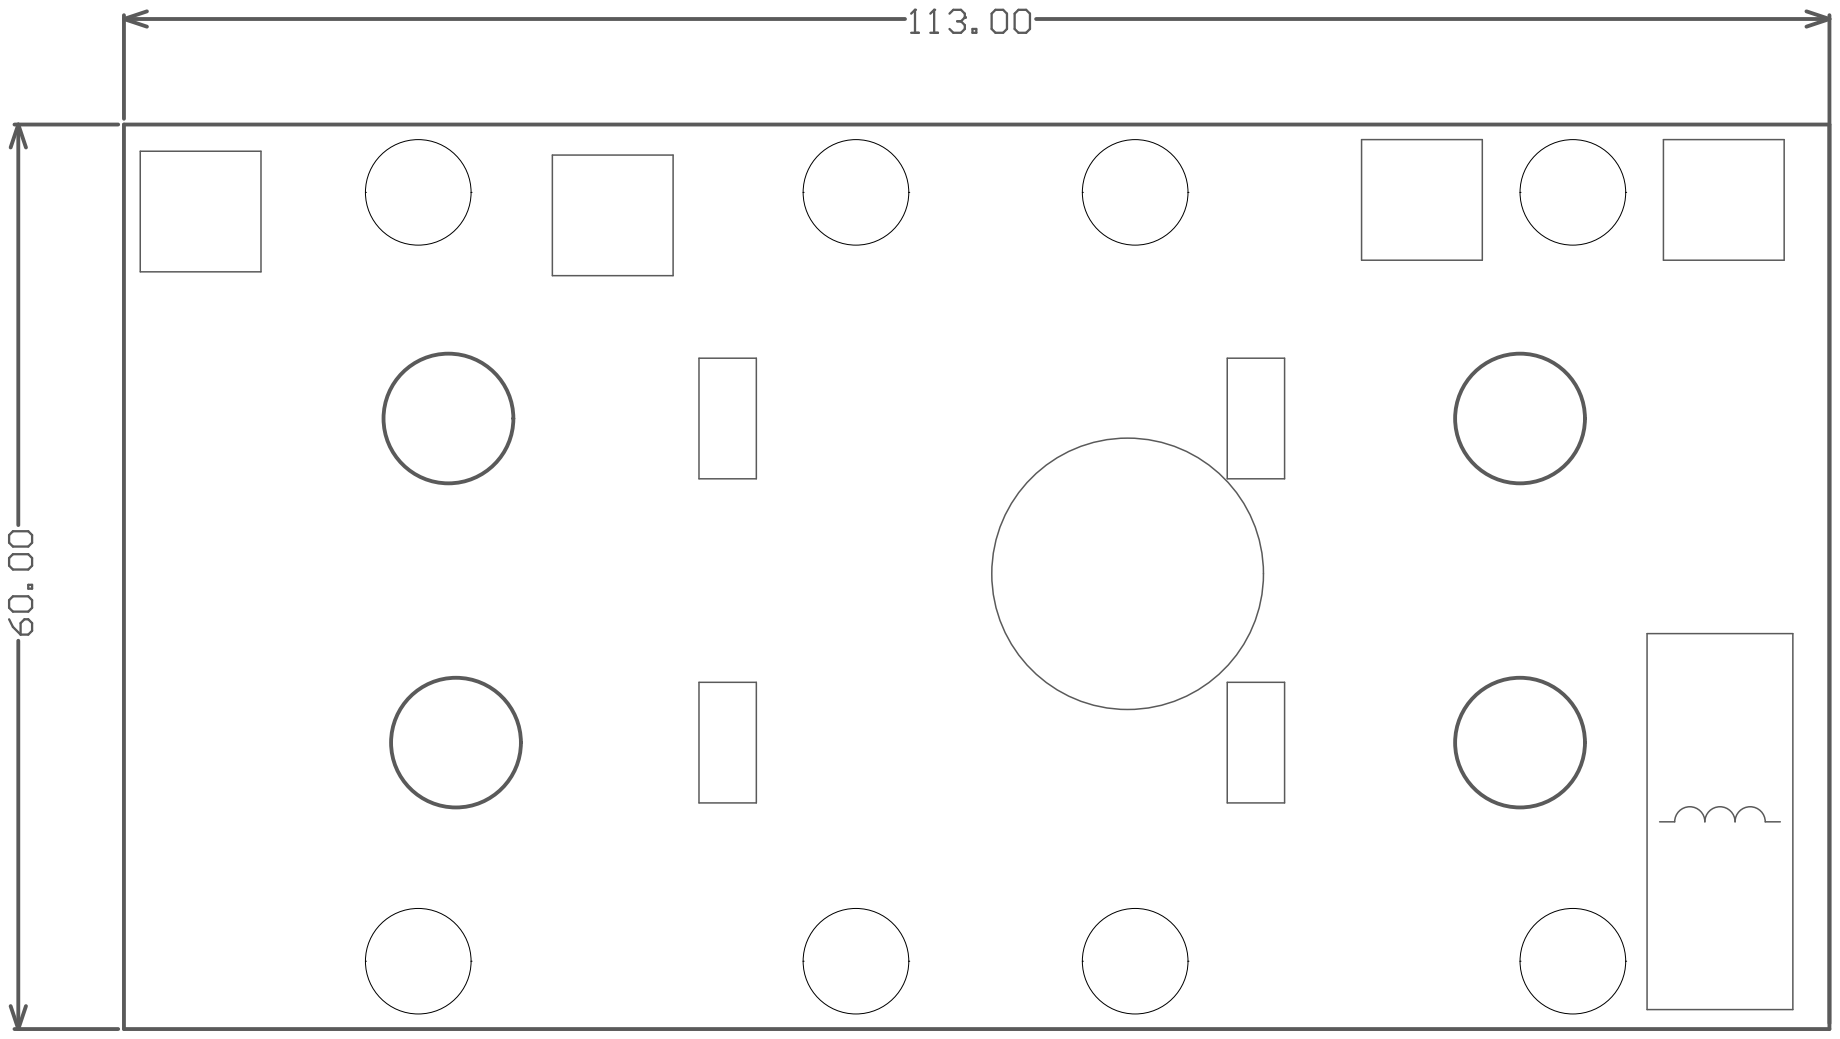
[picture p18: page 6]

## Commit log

2025-03-04 Накидав схему. Лишився трансформатор.
    [main.SchDoc]
2025-03-05 Додав трансформатор + Діоди + Мосфети
    [main.SchDoc, pcb_2Layer.PcbDoc]
2025-03-11 Окремо плата силова і плата ШІМ контроллера.
    [CTLR.SchDoc, CTRL.PcbDoc, CTRL.PrjPcb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]
2025-03-11 Попередньо розставив компоненти на платі.
    [PWR.SchDoc, pcb_2Layer.PcbDoc]
2025-03-12 PWR-Плату розтрасував
    [CTLR.SchDoc, PWR.SchDoc]
2025-03-13 На PWR додав снабери на MOSFET + 3 шунта в паралель + індикація напруги + нагрузеп на вихід
    [CTLR.SchDoc, CTRL.PcbDoc, CTRL.PrjPcb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]
2025-03-13 Додав FP на PWR
    [PWR.SchDoc]
2025-03-13 Revert "Додав FP на PWR"
    This reverts commit 00b5e450cb138fad2427b72619766734b58924ad.
    [PWR.SchDoc]
2025-03-13 Додав FP
    [PWR.SchDoc]
2025-03-14 Фікси перед виробнитцтвом.
    [Bill of Materials - CTRL.v1.xlsx, Bill of Materials - PWR.v1.xlsx, CTLR.SchDoc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]
2025-03-30 Фікси на карті пайки.
    [CTRL.PcbDoc, PWR.SchDoc]
2025-03-30 + Монтажні схеми
2025-04-14 Пофіксив монтажку і розрахунок трансформатора.
    [CTLR.SchDoc, CTRL.PcbDoc]
2025-04-15 Фікси
    [CTRL.PcbDoc]
2025-04-15 Додав фото зібраного девайсу
2025-04-16 Додав папку з STP
